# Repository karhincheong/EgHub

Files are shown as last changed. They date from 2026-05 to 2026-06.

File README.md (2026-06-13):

# Eg USB Hub

A 4-port output USB Hub keychain in the shape of an egg as a tribute to my friends. Main IC being CoreChips SL2.1S

## Motivation

This project is meant to be a try-out project for Fallout. It is to function as a primer for me to learn to make/design a PCB and at the same time make something useful.

## BOM

### Components List

<!-- prettier-ignore-start -->

|Item|Description|Quantity|Unit Price (USD)|Total Price (USD)|URL|Notes|
|---|---|---|---|---|---|---|
|Capacitor|0402 1 uF|16|0.0038|0.380|https://www.lcsc.com/product-detail/C29266.html|MOQ=100|
||0402 100 nF|16|0.0014|0.14|https://www.lcsc.com/product-detail/C14663.html|MOQ=100|
|Resistor|0603 5.1 kΩ|12|0.0016|0.16|https://www.lcsc.com/product-detail/C23186.html|MOQ=100|
|USB-A Receptacle||4|0.0665|0.665|https://www.lcsc.com/product-detail/C668591.html|MOQ=10|
|USB-C Receptacle||6|0.0741|1.482|https://www.lcsc.com/product-detail/C2765186.html|MOQ=20|
|CoreChips SL2.1S ||2|0.2849|1.4245|https://www.lcsc.com/product-detail/C2684433.html|MOQ=5|
|USBLC6-2SC6 ||16|0.154|3.080|https://www.lcsc.com/product-detail/C7519.html|MOQ=20|
|PCB (JLCPCB) Order||1|2.0000|2.0000|https://www.jlcpcb.com|MOQ=5|
||||||||
|TOTAL (for 2 units)||||9.33|||
|Component Cost per Unit||||4.67|||

<!-- prettier-ignore-end -->

### Additional Costs Incurred

| Item | Description | Price (USD) |
| --- | --- | --- |
| Shipping | UPS Worldwide Express Saver | 9.24 |

## Assembly Instructions

File Structure

| Folder | Description |
| --- | --- |
| `kicad/` | Files generated in KiCAD |
| `3d` | 3D Mechanical Models for the case and the PCB |

1. Print out the top and bottom covers using a 3D Printer.
2. Screw M3 screws into the 3 screw holes to an adequate tightness such that it doesnt damage the USB receptacles. Take note of the postition of the input USB-C.

## Schematic Diagram

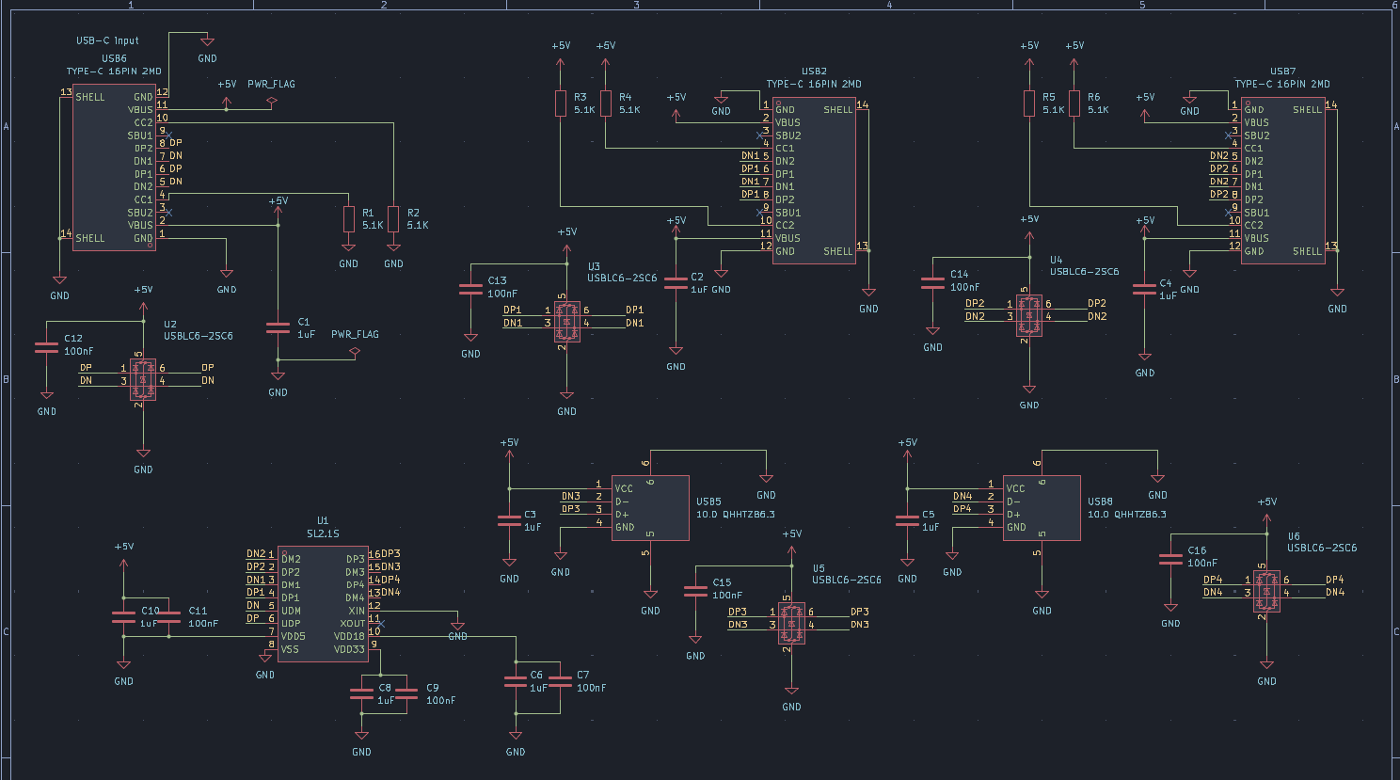
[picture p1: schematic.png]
Schematics


## PCB Layout

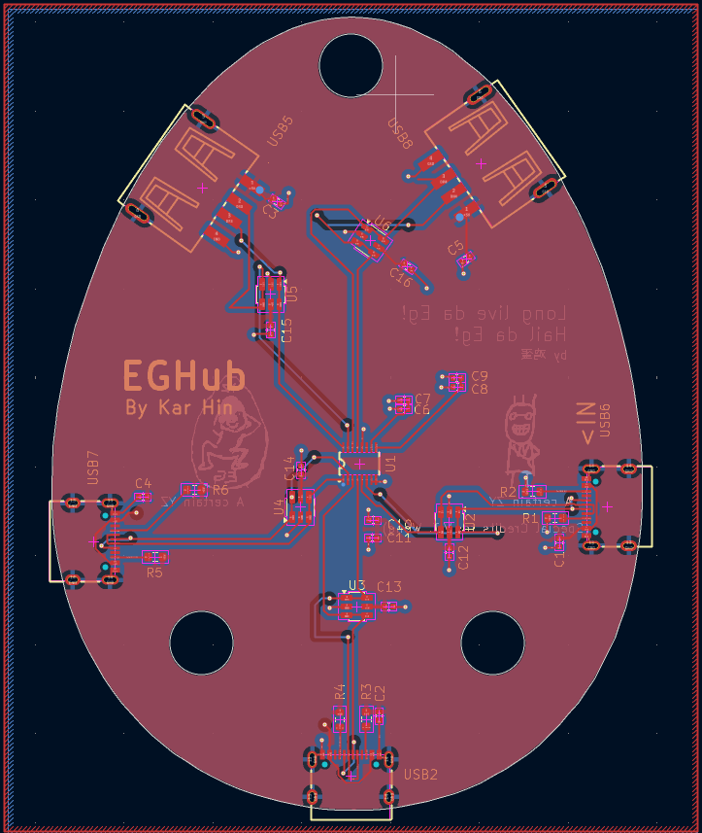
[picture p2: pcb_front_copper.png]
Layout


## PCB Render

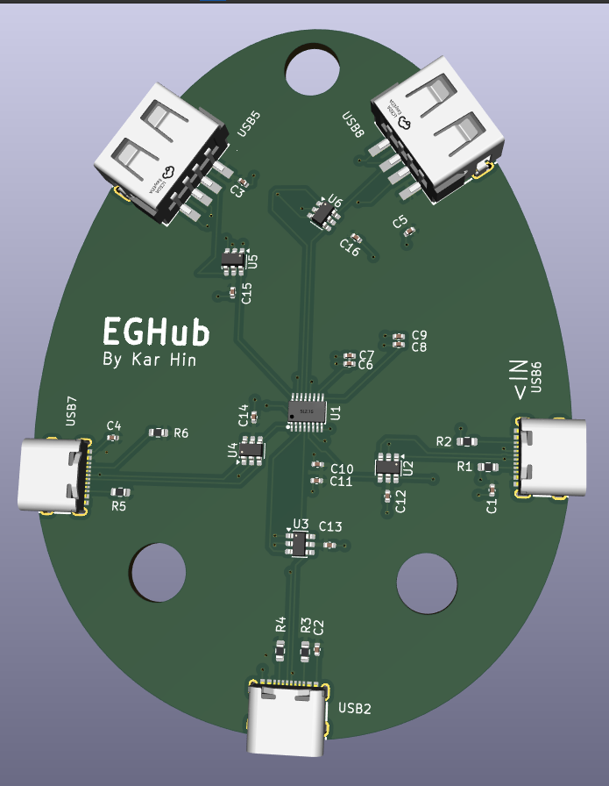
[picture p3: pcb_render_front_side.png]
PCB Render


## Case Render

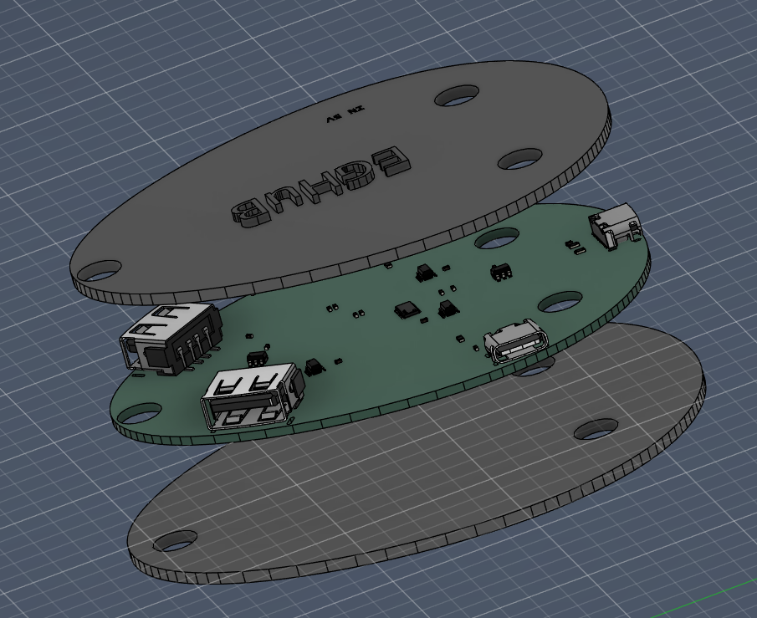
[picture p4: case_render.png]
Case Render


## Project Zine

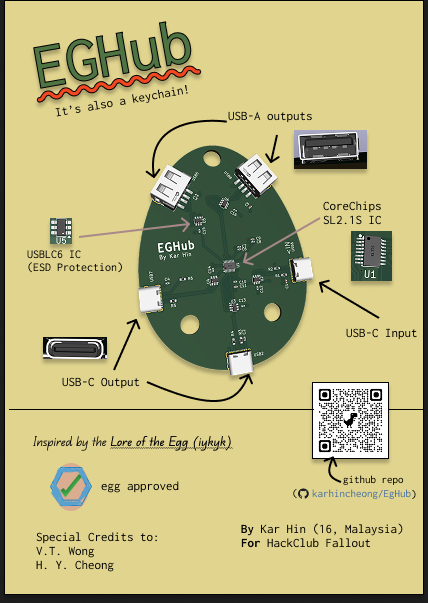
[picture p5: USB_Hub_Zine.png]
Project Zine


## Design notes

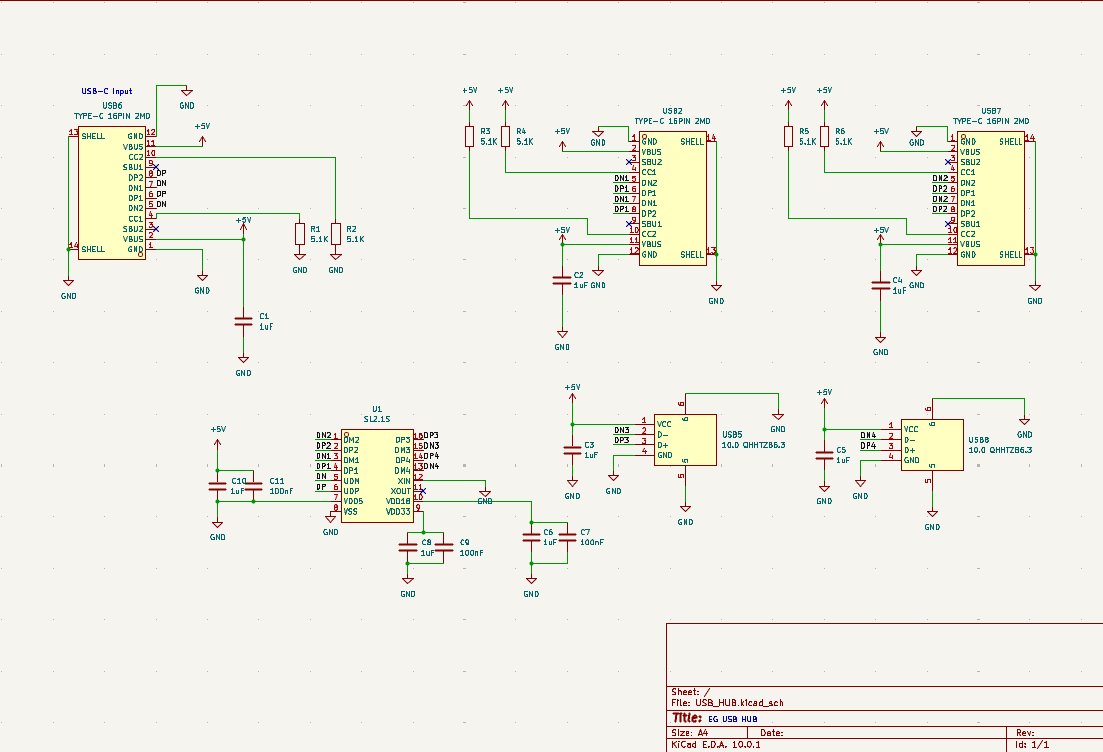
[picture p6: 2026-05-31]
image.png

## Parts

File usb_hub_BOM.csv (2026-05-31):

Item | Description | Quantity | Unit Price (USD) | Total Price (USD) | URL | Notes
Capacitor | 0402 1 uF | 16 | 0.0035 | 0.0560 | https://www.lcsc.com/product-detail/C29266.html | MOQ=100, Actual needed = 40
 | 0402 100 nF | 6 | 0.0014 | 0.0084 | https://www.lcsc.com/product-detail/C14663.html | MOQ=100, Actual needed = 15
Resistor | 0603 5.1 kê | 12 | 0.0016 | 0.0192 | https://www.lcsc.com/product-detail/C23186.html | MOQ=100, Actual needed = 30
USB-A Receptacle |  | 4 | 0.0665 | 0.2660 | https://www.lcsc.com/product-detail/C668591.html | MOQ=10
USB-C Receptacle |  | 6 | 0.0741 | 0.4446 | https://www.lcsc.com/product-detail/C2765186.html | MOQ=20, Actual needed = 15
CoreChips SL2.1S |  | 2 | 0.2849 | 0.5698 | https://www.lcsc.com/product-detail/C2684433.html | MOQ=5
PCB (JLCPCB) Order |  | 1 | 2.0000 | 2.0000 | https://www.jlcpcb.com | MOQ=5
TOTAL (for 2 units) |  |  |  | 3.3640
Cost per Unit |  |  |  | 1.682

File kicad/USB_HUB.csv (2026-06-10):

Reference | Qty | Value | DNP | Footprint | Datasheet | LCSC Part
C1,C2,C3,C4,C5,C6,C8,C10 | 8 | 1uF |  | Capacitor_SMD:C_0402_1005Metric
C7,C9,C11,C12,C13,C14,C15,C16 | 8 | 100nF |  | Capacitor_SMD:C_0402_1005Metric
R1,R2,R3,R4,R5,R6 | 6 | 5.1K |  | Resistor_SMD:R_0603_1608Metric
U1 | 1 | SL2.1S |  | easyeda2kicad:SSOP-16_L4.6-W2.6-P0.53-LS4.0-BL | https://www.lcsc.com/datasheet/C2684433.pdf | C2684433
U2,U3,U4,U5,U6 | 5 | USBLC6-2SC6 |  | Package_TO_SOT_SMD:SOT-23-6 | https://www.st.com/resource/en/datasheet/usblc6-2.pdf
USB2,USB6,USB7 | 3 | TYPE-C 16PIN 2MD |  | easyeda2kicad:USB-C-SMD_TYPE-C-6PIN-2MD-073 | https://www.lcsc.com/datasheet/C2765186.pdf | C2765186
USB5,USB8 | 2 | 10.0 QHHTZB6.3 |  | easyeda2kicad:USB-A-TH_10.0QHHTZB6.3 | https://www.lcsc.com/datasheet/C668591.pdf | C668591

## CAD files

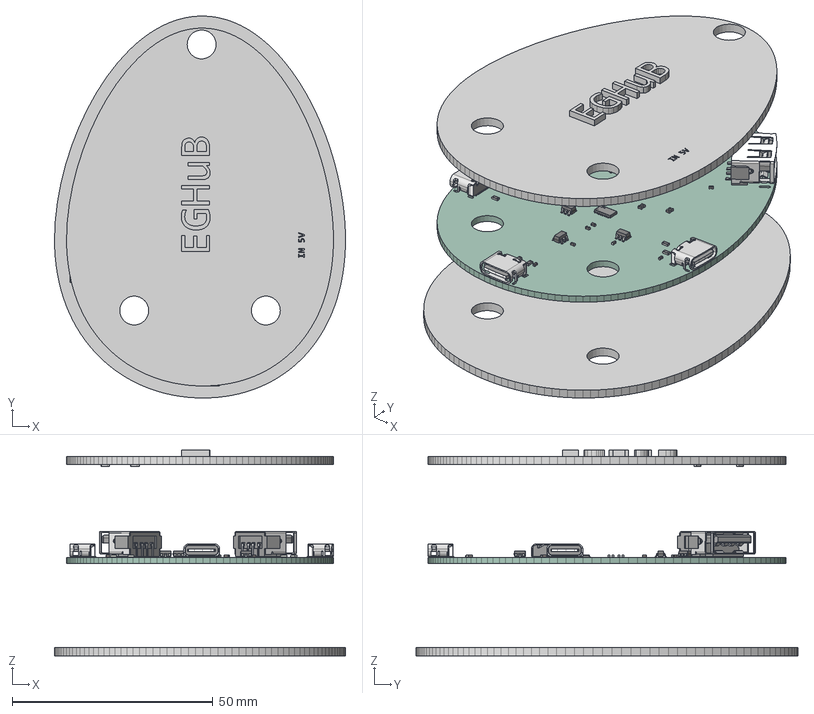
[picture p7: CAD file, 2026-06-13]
3d/usbhubcasesandwich.step
72.5 x 95.2 x 51.2 mm
C_0402_1005Metric x 11
R_0603_1608Metric x 6
USB-C-SMD_TYPE-C-6PIN-2MD-073 x 3
SOT-23-6 x 5
C_0402_1005Metric_1 x 5
USB-A-TH_10.0QHHTZB6.3 x 2
SSOP-16_L4.6-W2.6-P0.53-LS4.0-BL
USB_HUB_PCB

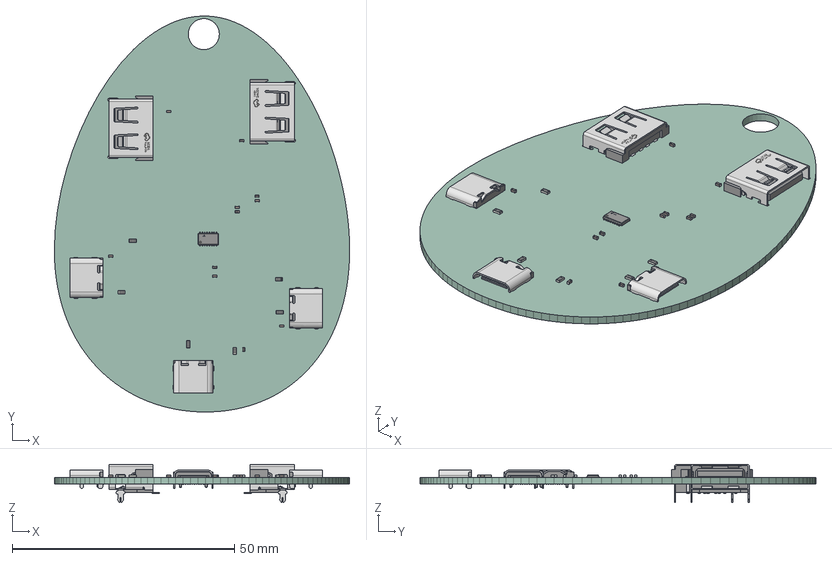
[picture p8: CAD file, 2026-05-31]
pcb3d.step
66.5 x 89.2 x 8.60 mm
C_0402_1005Metric x 11
R_0603_1608Metric x 6
USB-C-SMD_TYPE-C-6PIN-2MD-073 x 3
USB-A-TH_10.0QHHTZB6.3 x 2
SSOP-16_L4.6-W2.6-P0.53-LS4.0-BL
USB_HUB_PCB

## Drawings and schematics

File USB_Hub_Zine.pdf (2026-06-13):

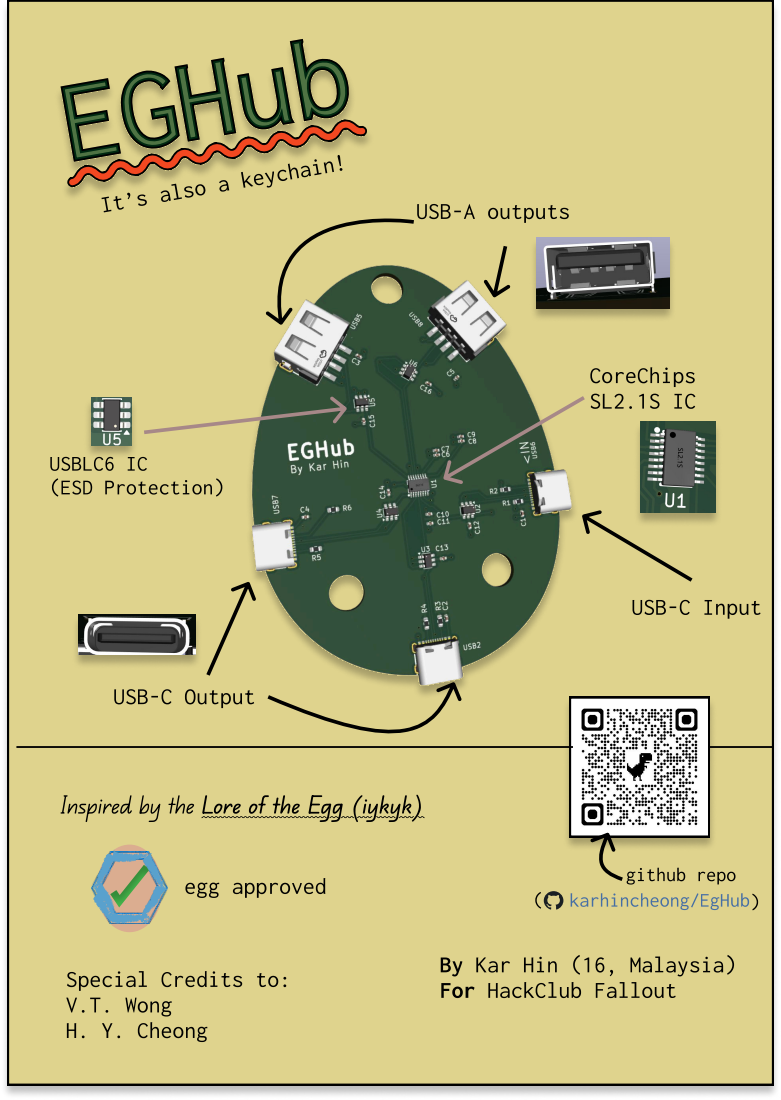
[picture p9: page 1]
EGHub; USB-A outputs; CoreChips; USBLC6 IC (ESD Protection); USB-C Input; USB-C Output; egg approved; github repo; karhincheong/EgHub)

It’s also a keychain!

Inspired by the Lore of the Egg (iykyk)

By Kar Hin (16, Malaysia)
For HackClub Fallout

Special Credits to:
V.T. Wong
H. Y. Cheong

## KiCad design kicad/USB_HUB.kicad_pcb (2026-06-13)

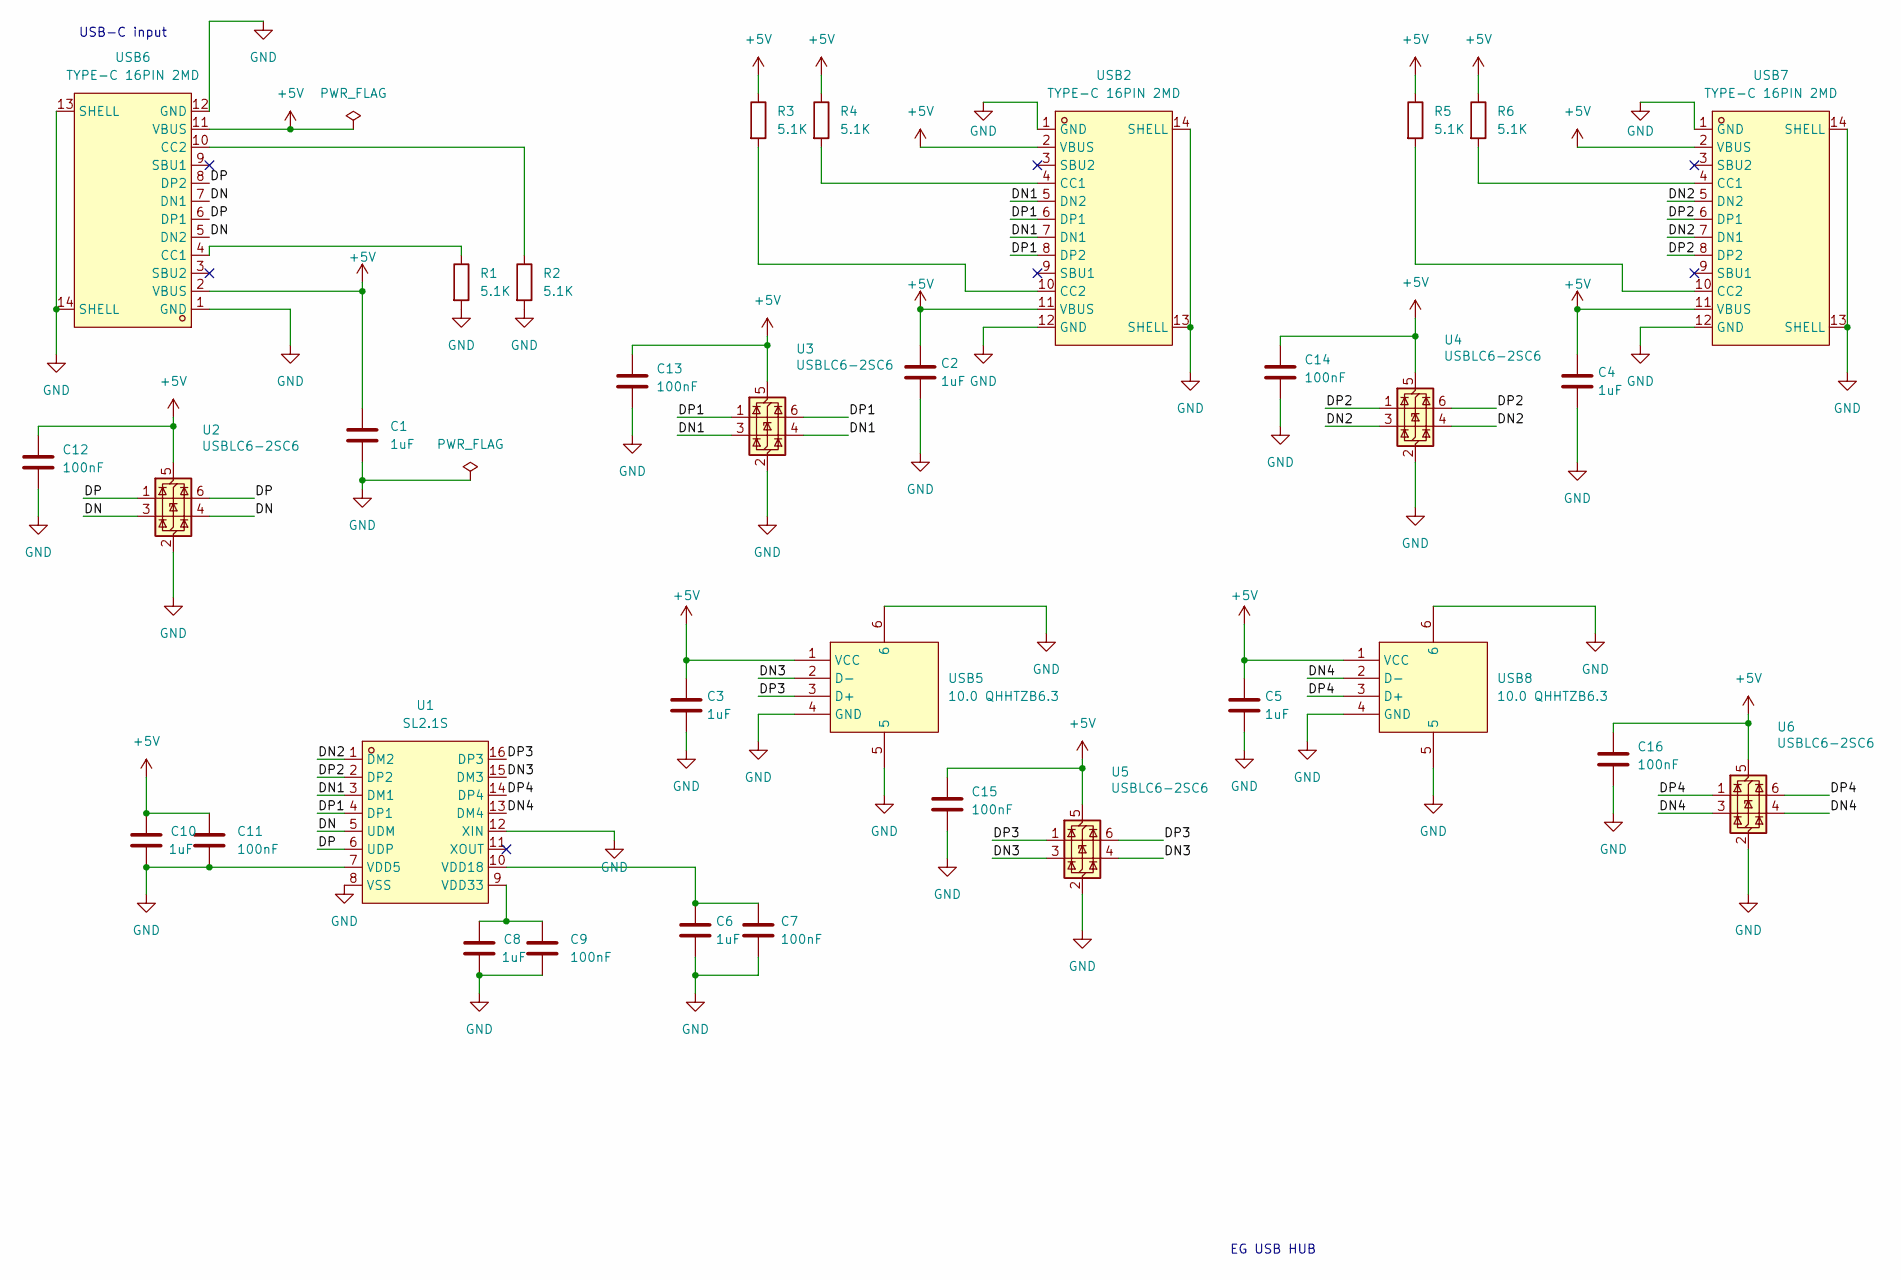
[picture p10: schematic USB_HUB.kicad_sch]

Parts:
C1, C2, C3, C4, C5, C6, C8, C10: 1uF; C_0402_1005Metric
C7, C9, C11, C12, C13, C14, C15, C16: 100nF; C_0402_1005Metric
R1, R2, R3, R4, R5, R6: 5.1K; R_0603_1608Metric
U1: SL2.1S; SSOP-16_L4.6-W2.6-P0.53-LS4.0-BL; MPN SL2.1s; LCSC Part C2684433
U2, U3, U4, U5, U6: USBLC6-2SC6; SOT-23-6
USB2, USB6, USB7: TYPE-C 16PIN 2MD; USB-C-SMD_TYPE-C-6PIN-2MD-073; MPN TYPE-C 16PIN 2MD(073); LCSC Part C2765186
USB5, USB8: 10.0 QHHTZB6.3; USB-A-TH_10.0QHHTZB6.3; MPN 10.0 QHHTZB6.3; LCSC Part C668591

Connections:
+5V: C1.1, C2.1, C3.1, C4.1, C5.1, C10.1, C11.1, C12.1, C13.1, C14.1, C15.1, C16.1, R3.1, R4.1, R5.1, R6.1, U2.5 (VBUS), U3.5 (VBUS), U4.5 (VBUS), U5.5 (VBUS), U6.5 (VBUS), USB2.2 (VBUS), USB2.11 (VBUS), USB5.1 (VCC), USB6.2 (VBUS), USB6.11 (VBUS), USB7.2 (VBUS), USB7.11 (VBUS), USB8.1 (VCC)
/DN: U1.5 (UDM), U2.3 (I/O2), U2.4 (I/O2), USB6.5 (DN2), USB6.7 (DN1)
/DN1: U1.3 (DM1), U3.3 (I/O2), U3.4 (I/O2), USB2.5 (DN2), USB2.7 (DN1)
/DN2: U1.1 (DM2), U4.3 (I/O2), U4.4 (I/O2), USB7.5 (DN2), USB7.7 (DN1)
/DN3: U1.15 (DM3), U5.3 (I/O2), U5.4 (I/O2), USB5.2 (D-)
/DN4: U1.13 (DM4), U6.3 (I/O2), U6.4 (I/O2), USB8.2 (D-)
/DP: U1.6 (UDP), U2.1 (I/O1), U2.6 (I/O1), USB6.6 (DP1), USB6.8 (DP2)
/DP1: U1.4 (DP1), U3.1 (I/O1), U3.6 (I/O1), USB2.6 (DP1), USB2.8 (DP2)
/DP2: U1.2 (DP2), U4.1 (I/O1), U4.6 (I/O1), USB7.6 (DP1), USB7.8 (DP2)
/DP3: U1.16 (DP3), U5.1 (I/O1), U5.6 (I/O1), USB5.3 (D+)
/DP4: U1.14 (DP4), U6.1 (I/O1), U6.6 (I/O1), USB8.3 (D+)
GND: C1.2, C2.2, C3.2, C4.2, C5.2, C6.2, C7.2, C8.2, C9.2, C10.2, C11.2, C12.2, C13.2, C14.2, C15.2, C16.2, R1.2, R2.2, U1.7 (VDD5), U1.8 (VSS), U1.12 (XIN), U2.2 (GND), U3.2 (GND), U4.2 (GND), U5.2 (GND), U6.2 (GND), USB2.1 (GND), USB2.12 (GND), USB2.13 (SHELL), USB2.14 (SHELL), USB5.4 (GND), USB5.5, USB5.6, USB6.1 (GND), USB6.12 (GND), USB6.13 (SHELL), USB6.14 (SHELL), USB7.1 (GND), USB7.12 (GND), USB7.13 (SHELL), USB7.14 (SHELL), USB8.4 (GND), USB8.5, USB8.6
unnamed: C6.1, C7.1, U1.10 (VDD18)
unnamed: C8.1, C9.1, U1.9 (VDD33)
unnamed: R4.2, USB2.4 (CC1)
unnamed: R3.2, USB2.10 (CC2)
unnamed: R1.1, USB6.4 (CC1)
unnamed: R2.1, USB6.10 (CC2)
unnamed: R6.2, USB7.4 (CC1)
unnamed: R5.2, USB7.10 (CC2)

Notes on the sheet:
EG USB HUB
USB-C input

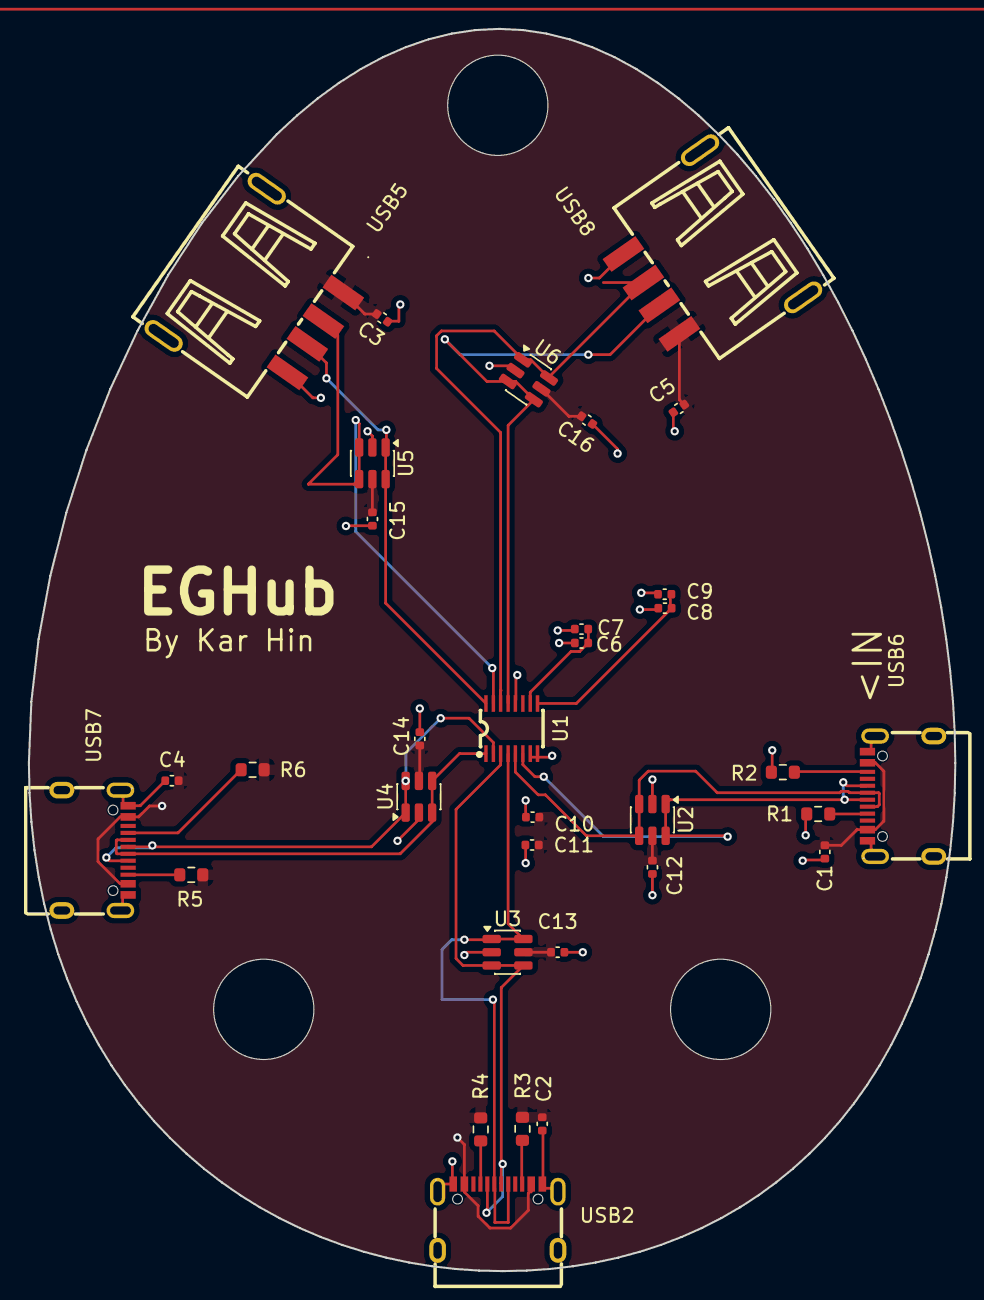
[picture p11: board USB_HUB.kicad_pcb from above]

Board: 2 copper layers, 66.5 x 89.2 mm, 33 parts (0 on the bottom side), 20 nets.

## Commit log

2026-05-31 Fixed Readme and Zine
    [USB_HUB-B_Cu.gbr, USB_HUB-B_Mask.gbr, USB_HUB-B_Paste.gbr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]
2026-05-31 Reorganised FIles
    [USB_HUB.csv, USB_HUB.kicad_pcb, USB_HUB.kicad_sch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]
2026-06-10 Updated board design to include ESD. Not changed: Zine, README except BOM
    [USB_HUB-B_Cu.gbr, USB_HUB-B_Mask.gbr, USB_HUB-B_Paste.gbr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]
2026-06-13 Fixes to review requirements check
    [USB_HUB.kicad_pcb, USB_HUB.kicad_sch, usbhubcasesandwich.step]
2026-06-13 changed folder name for req check warnings
    [USB_HUB.csv, USB_HUB.kicad_pcb, USB_HUB.kicad_sch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]
2026-06-13 Changed readme to include detailed assembly instructions
2026-06-14 Readded Gerber Files
    [USB_HUB-B_Cu.gbr, USB_HUB-B_Mask.gbr, USB_HUB-B_Paste.gbr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]
